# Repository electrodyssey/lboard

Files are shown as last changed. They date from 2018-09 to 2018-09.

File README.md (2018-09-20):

# lboard
Very basic Spartan-6 LX9 board with a plenty of GPIO
This was my very first attempt to dive into fpga world.
Board is working, however it has a few disadvantages:
Configuration is loaded via slave select-map setup which occupies a lot of fpga pins
Configuration is slow - around 3 seconds. That's an outcome of Atmega's slow gpio
There is no switched step-down psu on the board, power is regulated with a linear ldo

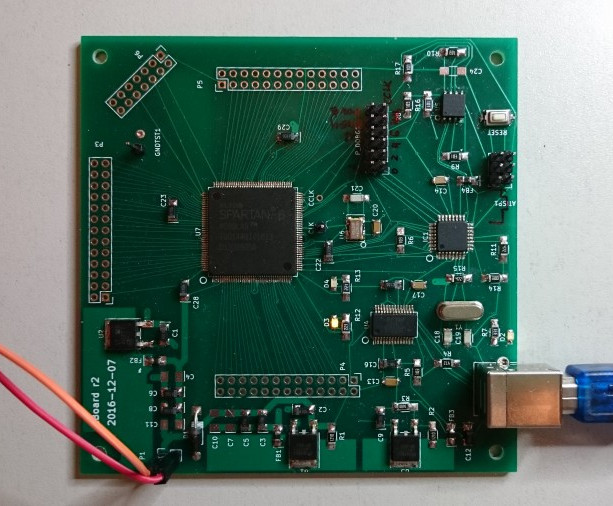
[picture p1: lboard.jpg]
lboard


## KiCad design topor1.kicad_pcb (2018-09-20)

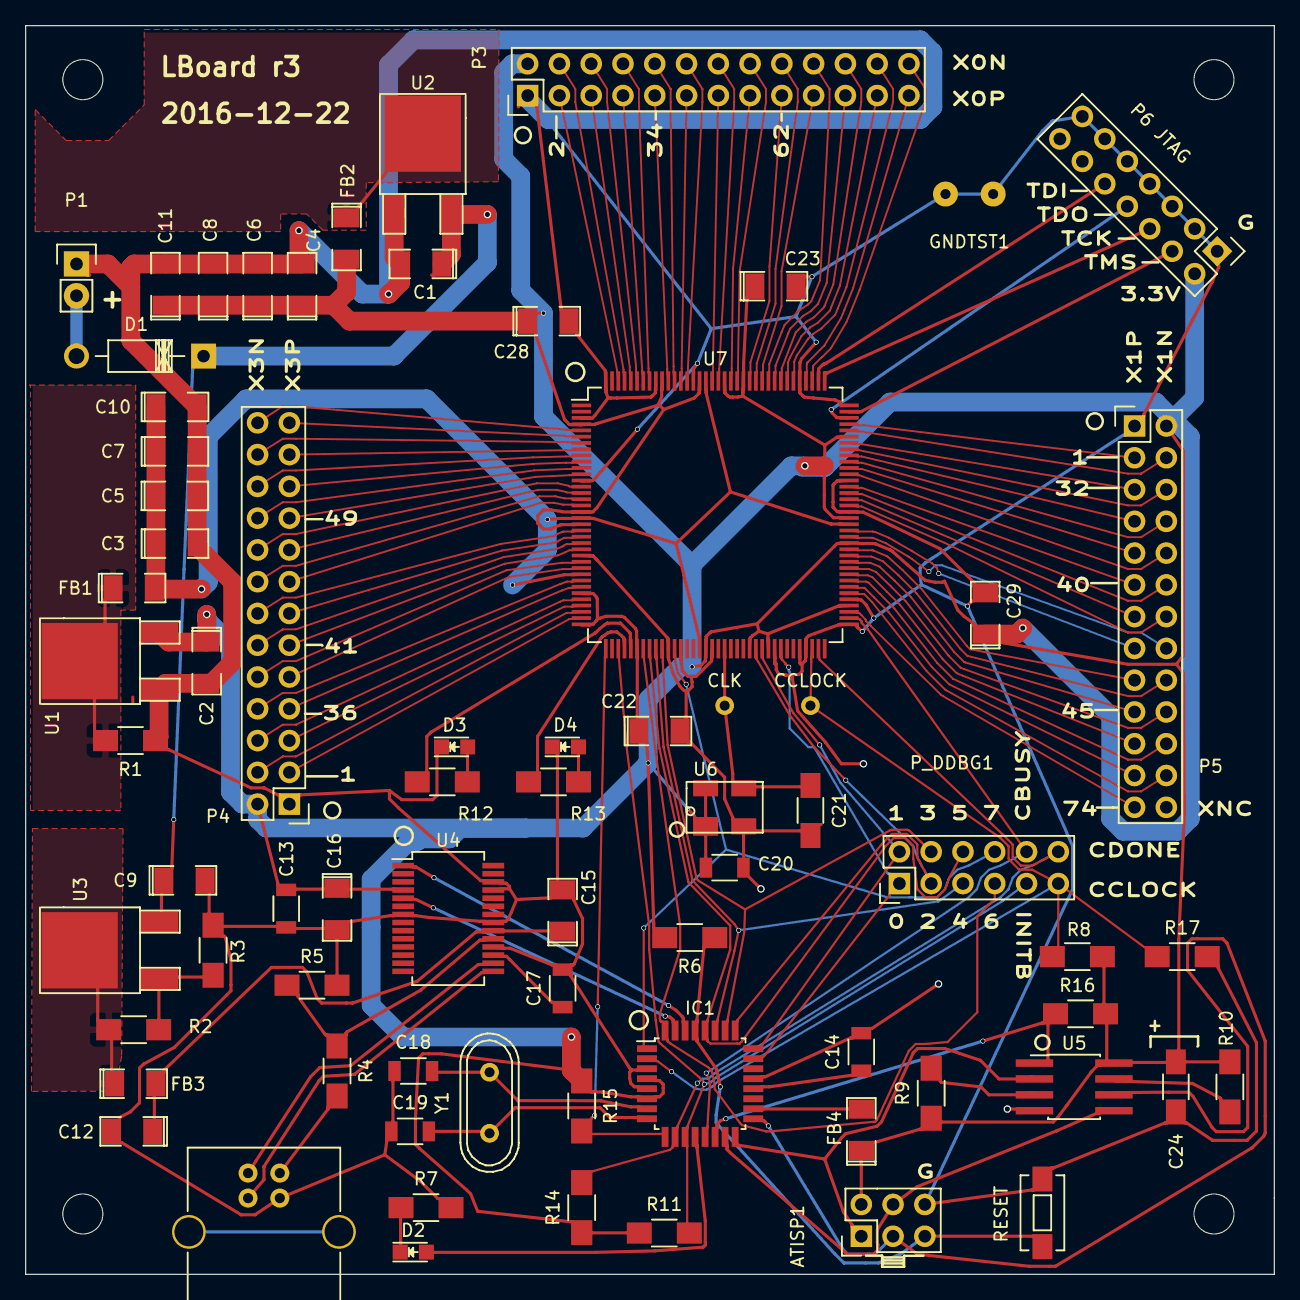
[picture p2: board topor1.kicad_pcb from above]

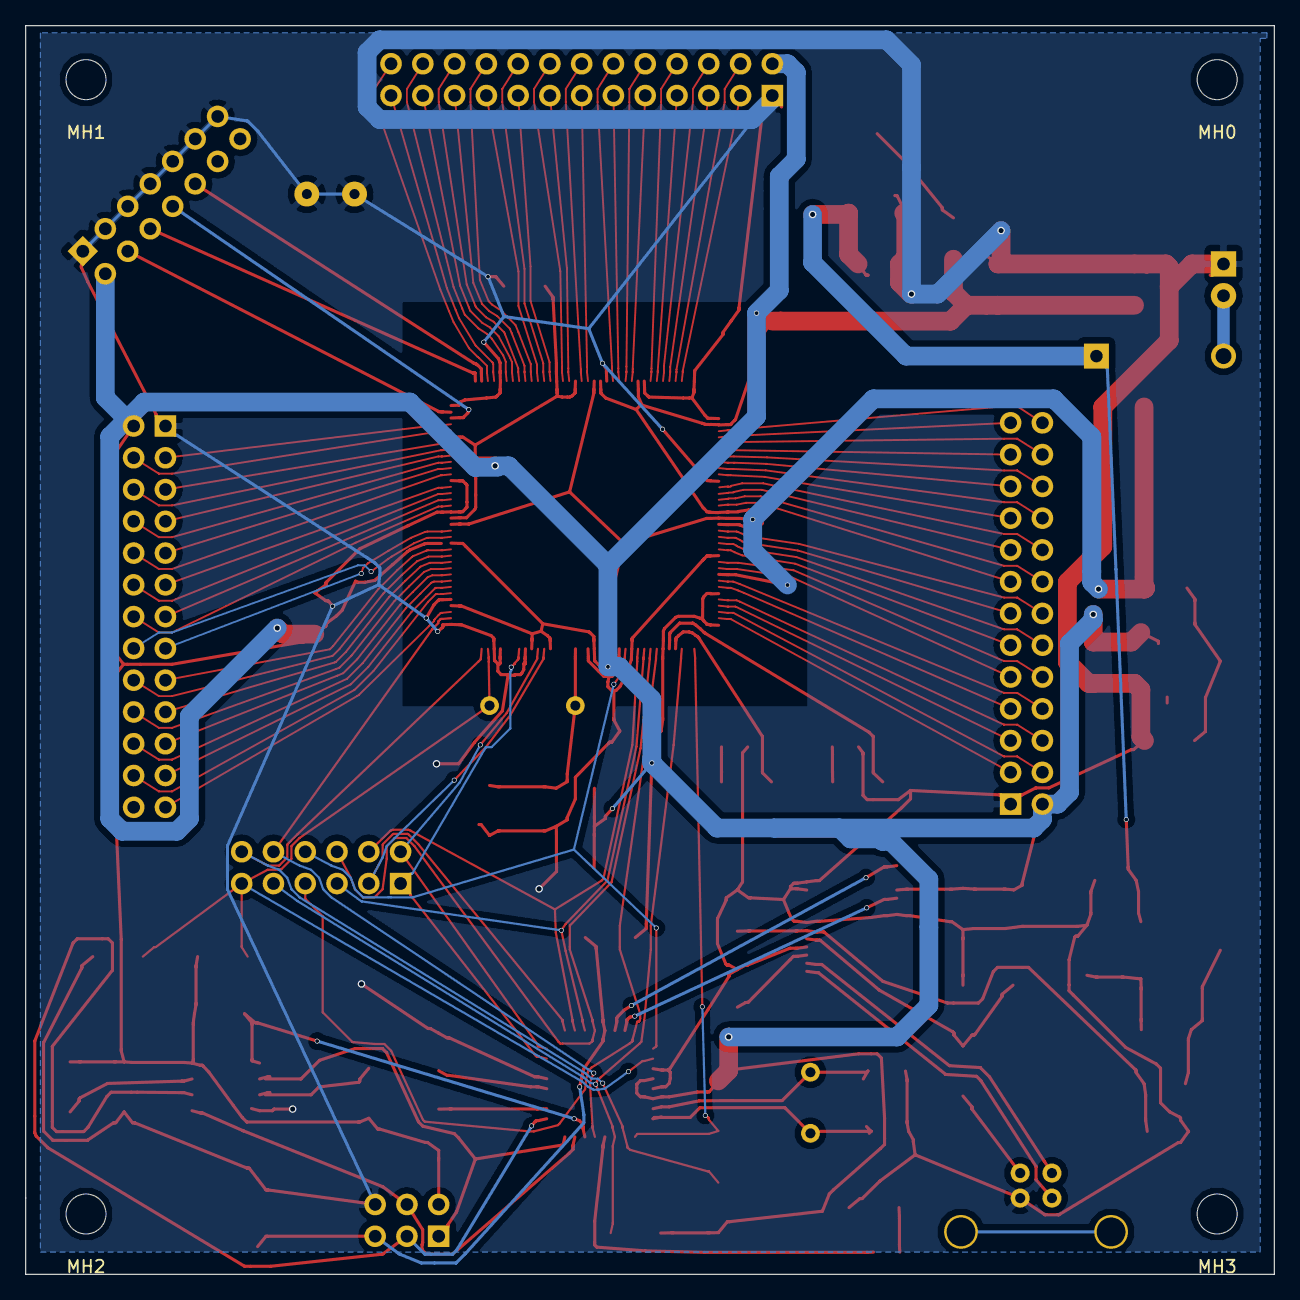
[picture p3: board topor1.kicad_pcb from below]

Board: 2 copper layers, 99.8 x 99.8 mm, 76 parts (4 on the bottom side), 123 nets.

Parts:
ATISP1: AVR-ISP-6; Pin_Header_Straight_2x03
C1, C2, C5, C6, C7, C8, C9, C10, C11, C22, C23, C28, C29: 10uF; SMD-1206_Pol
C3, C4, C12, C15, C16: 1uF; SMD-1206_Pol
C13, C14, C17, C20: 0.1; C_1206
C18, C19: 15pF; C_1206
C21: 15pF; C_1206_HandSoldering
C24: 1uF; C_1206_HandSoldering
CCLOCK: TEST_1P; Measurement_Point_Round-TH_Small
CLK: TEST_1P; Measurement_Point_Round-TH_Small
D1: D_Rectifier; Diode_DO-41_SOD81_Horizontal_RM10
D2: LED; LED_0805
D3, D4: Led_Small; LED_0805
FB1, FB2, FB3, FB4: FERRITE; SMD-1206_Pol
GNDTST1: TEST; SolderWirePad_2x_0-8mmDrill
IC1: ATMEGA168-A; TQFP-32_7x7mm_Pitch0.8mm
MH0, MH1, MH2, MH3: MountingHole_3.2mm_M3
P1: CONN_01X02_PWR; Pin_Header_Straight_1x02
P2: USB_B
P3: CONN_02X13_X0; Pin_Header_Straight_2x13
P4: CONN_02X13_X3; Pin_Header_Straight_2x13
P5: CONN_02X13_X1; Pin_Header_Straight_2x13
P6 JTAG: CONN_02X07_JTAG; Pin_Header_Straight_2x07
P_DDBG1: CONN_02X06; Pin_Header_Straight_2x06
R1, R2: 121; R_1206_HandSoldering
R3: 365; R_1206_HandSoldering
R4, R11, R15: 4k7; R_1206_HandSoldering
R5, R6, R8, R9, R10: 10k; R_1206_HandSoldering
R7: 220; R_1206_HandSoldering
R12, R13, R14: 330; R_1206_HandSoldering
R16, R17: 100; R_1206_HandSoldering
RESET: SW_RESET; SW_SPST_EVQPE1
U1, U3: AP1117_ADJ; TO-252-2Lead
U2: AP1117_33; TO-252-2Lead
U4: FT232RL; SSOP-28_5.3x10.2mm_Pitch0.65mm
U5: M25P16-VME; SOIC-8_5.49x5.49mm_Pitch1.27mm
U6: ECS-3963; ECS396x
U7: XC6SLX9-TQG144; LQFP-144_20x20mm_Pitch0.5mm
Y1: 11.059MHz; Crystal_HC49-U_Vertical

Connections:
+1V2: C3.1, C5.1, C7.1, C10.1, FB1.2, U7.19, U7.28, U7.52, U7.89, U7.128
+3V3: ATISP1.2, C2.1, C4.1, C6.1, C8.1, C11.1, C13.1, C16.1, C20.1, C22.1, C23.1, C24.2, C28.1, C29.1, FB2.2, FB4.1, IC1.4, IC1.6, P3.2, P4.2, P5.2, P6 JTAG.2, R6.2, R8.2, R9.1, R10.1, R11.1, R14.1, R15.1, R16.1, U1.3, U4.4, U5.8, U6.1, U6.4, U7.4, U7.18, U7.20, U7.31, U7.36, U7.42, U7.53, U7.60, U7.63, U7.76, U7.86, U7.90, U7.103, U7.122, U7.125, U7.129, U7.135
+5V: C12.1, C15.1, FB3.2, U4.20
/mcu/CBUSY: IC1.13, P_DDBG1.10, U7.74
/mcu/CCLOCK: CCLOCK.1, IC1.2, P_DDBG1.11, R16.2, R17.1, U7.70
/mcu/CD0: IC1.23, P_DDBG1.1, U7.65
/mcu/CD1: IC1.24, P_DDBG1.2, U7.62
/mcu/CD2: IC1.25, P_DDBG1.3, U7.61
/mcu/CD3: IC1.26, P_DDBG1.4, U7.46
/mcu/CD4: IC1.27, P_DDBG1.5, U7.45
/mcu/CD5: IC1.28, P_DDBG1.6, U7.44
/mcu/CD6: IC1.32, P_DDBG1.7, U7.43
/mcu/CD7: IC1.1, P_DDBG1.8, U7.48
/mcu/CDONE: IC1.10, P_DDBG1.12, R14.2, U7.71
/mcu/CINITB: IC1.11, P_DDBG1.9, R11.2, U7.39
/mcu/CPROGB: IC1.9, R15.2, U7.37
/mcu/MISO: ATISP1.1, IC1.16, U5.2
/mcu/MOSI: ATISP1.4, IC1.15, U5.5
/spartan6/CLK_XO: C21.1, CLK.1, U6.3, U7.56
/spartan6/TCK: P6 JTAG.6, U7.109
/spartan6/TDI: P6 JTAG.10, U7.110
/spartan6/TDO: P6 JTAG.8, U7.106
/spartan6/TMS: P6 JTAG.4, U7.107
/spartan6/X0_L2_N: P3.4, U7.141
/spartan6/X0_L2_P: P3.3, U7.142
/spartan6/X0_L3_N: P3.6, U7.139
/spartan6/X0_L3_P: P3.5, U7.140
/spartan6/X0_L4_N: P3.8, U7.137
/spartan6/X0_L4_P: P3.7, U7.138
/spartan6/X0_L34_N: P3.10, U7.133
/spartan6/X0_L34_P: P3.9, U7.134
/spartan6/X0_L35_N: P3.12, U7.131
/spartan6/X0_L35_P: P3.11, U7.132
/spartan6/X0_L36_N: P3.14, U7.126
/spartan6/X0_L36_P: P3.13, U7.127
/spartan6/X0_L37_N: P3.16, U7.123
/spartan6/X0_L37_P: P3.15, U7.124
/spartan6/X0_L62_N: P3.18, U7.120
/spartan6/X0_L62_P: P3.17, U7.121
/spartan6/X0_L63_N: P3.20, U7.118
/spartan6/X0_L63_P: P3.19, U7.119
/spartan6/X0_L64_N: P3.22, U7.116
/spartan6/X0_L64_P: P3.21, U7.117
/spartan6/X0_L65_N: P3.24, U7.114
/spartan6/X0_L65_P: P3.23, U7.115
/spartan6/X0_L66_N: P3.26, U7.111
/spartan6/X0_L66_P: P3.25, U7.112
/spartan6/X1_L1_N: P5.4, U7.104
/spartan6/X1_L1_P: P5.3, U7.105
/spartan6/X1_L32_N: P5.6, U7.101
/spartan6/X1_L32_P: P5.5, U7.102
/spartan6/X1_L33_N: P5.8, U7.99
/spartan6/X1_L33_P: P5.7, U7.100
/spartan6/X1_L34_N: P5.10, U7.97
/spartan6/X1_L34_P: P5.9, U7.98
/spartan6/X1_L40_N: P5.12, U7.94
/spartan6/X1_L40_P: P5.11, U7.95
/spartan6/X1_L41_N: P5.14, U7.92
/spartan6/X1_L41_P: P5.13, U7.93
/spartan6/X1_L42_N: P5.16, U7.87
/spartan6/X1_L42_P: P5.15, U7.88
/spartan6/X1_L43_N: P5.18, U7.84
/spartan6/X1_L43_P: P5.17, U7.85
/spartan6/X1_L45_N: P5.20, U7.82
/spartan6/X1_L45_P: P5.19, U7.83
/spartan6/X1_L46_N: P5.22, U7.80
/spartan6/X1_L46_P: P5.21, U7.81
/spartan6/X1_L47_N: P5.24, U7.78
/spartan6/X1_L47_P: P5.23, U7.79
/spartan6/X1_L74_P: P5.25, U7.75
/spartan6/X3_L1_N: P4.4, U7.34
/spartan6/X3_L1_P: P4.3, U7.35
/spartan6/X3_L2_N: P4.6, U7.32
/spartan6/X3_L2_P: P4.5, U7.33
/spartan6/X3_L36_N: P4.8, U7.29
/spartan6/X3_L36_P: P4.7, U7.30
/spartan6/X3_L37_N: P4.10, U7.26
/spartan6/X3_L37_P: P4.9, U7.27
/spartan6/X3_L41_N: P4.12, U7.23
/spartan6/X3_L41_P: P4.11, U7.24
/spartan6/X3_L42_N: P4.14, U7.21
/spartan6/X3_L42_P: P4.13, U7.22
/spartan6/X3_L43_N: P4.16, U7.16
/spartan6/X3_L43_P: P4.15, U7.17
/spartan6/X3_L44_N: P4.18, U7.14
/spartan6/X3_L44_P: P4.17, U7.15
/spartan6/X3_L49_N: P4.20, U7.11
/spartan6/X3_L49_P: P4.19, U7.12
/spartan6/X3_L50_N: P4.22, U7.9
/spartan6/X3_L50_P: P4.21, U7.10
/spartan6/X3_L51_N: P4.24, U7.7
/spartan6/X3_L51_P: P4.23, U7.8
/spartan6/X3_L52_N: P4.26, U7.5
/spartan6/X3_L52_P: P4.25, U7.6
GND: ATISP1.6, C1.2, C2.2, C3.2, C4.2, C5.2, C6.2, C7.2, C8.2, C9.2, C10.2, C11.2, C12.2, C13.2, C14.2, C15.2, C16.2, C17.2, C18.1, C19.1, C20.2, C21.2, C22.2, C23.2, C24.1, C28.2, C29.2, D3.1, D4.1, GNDTST1.1, IC1.3, IC1.5, IC1.21, P1.1, P2.4, P3.1, P4.1, P5.1, P6 JTAG.1, P6 JTAG.3, P6 JTAG.5, P6 JTAG.7, P6 JTAG.9, P6 JTAG.11, P6 JTAG.13, R1.1, R3.2, R5.2, R7.2, R17.2, RESET.2, U1.1, U2.1, U4.7, U4.18, U4.21, U4.25, U4.26, U5.4, U6.2, U7.3, U7.13, U7.25, U7.47, U7.49, U7.54, U7.64, U7.68, U7.69, U7.73, U7.77, U7.91, U7.96, U7.108, U7.113, U7.130, U7.136, U7.144
unnamed: ATISP1.3, IC1.17, U5.6
unnamed: ATISP1.5, IC1.29, R6.1, RESET.1
unnamed: C14.1, IC1.20
unnamed: C17.1, U4.17
unnamed: C18.2, IC1.7, Y1.2
unnamed: C19.2, IC1.8, Y1.1
unnamed: D1.2, P1.2
unnamed: D2.1, R7.1
unnamed: D2.2, IC1.12
unnamed: D3.2, R12.2
unnamed: D4.2, R13.2
unnamed: FB1.1, R1.2, U1.2
unnamed: FB2.1, U2.2
unnamed: FB3.1, R2.1, U3.2
unnamed: FB4.2, IC1.18
unnamed: IC1.14, R8.1, U5.1
unnamed: IC1.30, U4.1
unnamed: IC1.31, U4.5
unnamed: P2.1, R4.2
unnamed: P2.2, U4.16
unnamed: P2.3, U4.15
unnamed: R2.2, R3.1, U3.1
unnamed: R4.1, R5.1, U4.19
unnamed: R9.2, U5.3
unnamed: R10.2, U5.7
unnamed: R12.1, U7.41
unnamed: R13.1, U7.40
VCC: C1.1, C9.1, D1.1, U2.3, U3.3

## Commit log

2016-12-07 Initial import
    [lboard.sch, mcu.sch, spartan6.sch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]
2016-12-12 minor changes in silkscreen
    [topor1.kicad_pcb]
2016-12-20 C24 was changed to an electrolytic capacitor
    [mcu.sch]
2016-12-20 Spartan-6 chip position was changed to avoid problems with a bent tracks. CD6 net was rerouted.
    [topor1.kicad_pcb]
2016-12-20 bumped revision number, made some minort track layout changes
    [lboard.sch, mcu.sch, spartan6.sch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]
2016-12-21 footprint of oscillator Y1 changed. Some silscreen changes
    [lboard.sch, mcu.sch, spartan6.sch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]
2016-12-22 New footprint for SOIC-8W.
    [topor1.kicad_pcb]
2016-12-22 ATMEGA168 description was changed to ATMEGA328P
    [mcu.sch]
2016-12-22 Silkscreen changes
    [topor1.kicad_pcb]
2016-12-22 correction in silkscreen
    [topor1.kicad_pcb]
